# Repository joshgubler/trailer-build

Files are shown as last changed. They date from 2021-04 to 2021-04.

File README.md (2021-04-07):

# Trailer Build

## Introduction

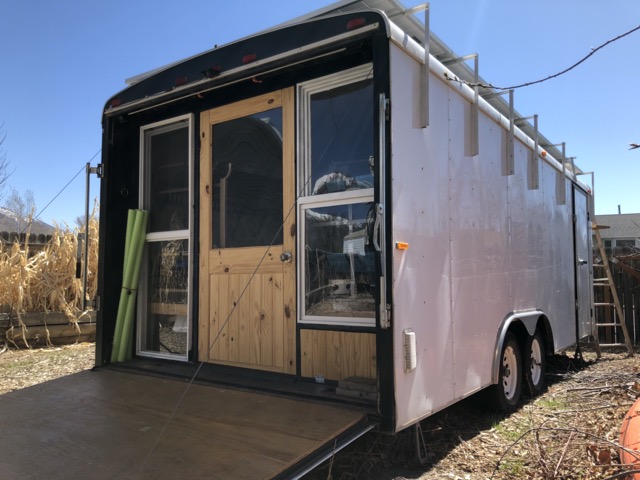
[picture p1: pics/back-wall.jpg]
back wall


It's an 8'x20' car hauler, converted into a travel trailer.

If I could change one thing, I would start with a lighter trailer. Car haulers have massive floor joists which just add unnecessary weight for a travel trailer. However, commercially manufactured travel trailers are poorly built, leak, and fall apart. Utility trailers don't have any of these problems. I expect this thing to last forever.

## Construction

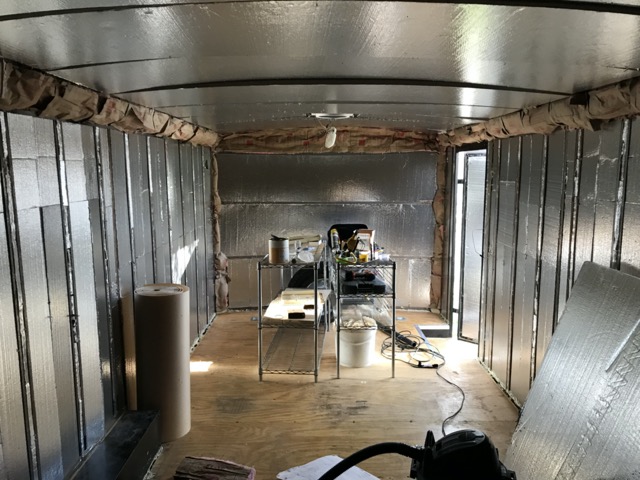
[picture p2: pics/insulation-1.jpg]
insulate spaces


The first thing we did was take all the paneling out and add insulation. 1" solid foam in the walls. 1.5" solid foam in the nose and roof. Batting in the curved corners.

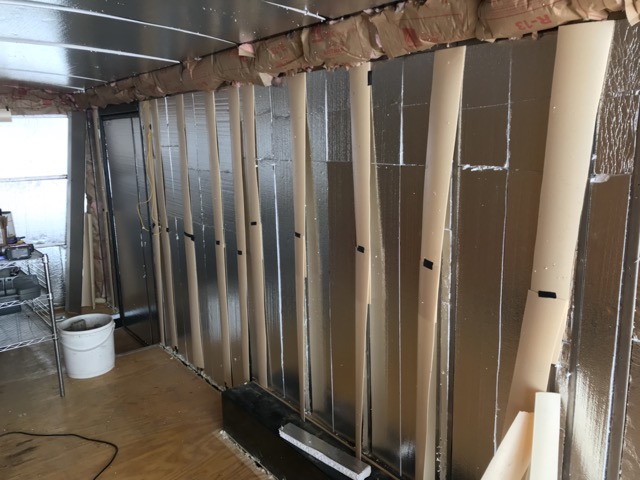
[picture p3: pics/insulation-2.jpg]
insulate metal


Then we covered all the exposed metal with foam strips. This cuts down on heat loss due to conduction through the walls.

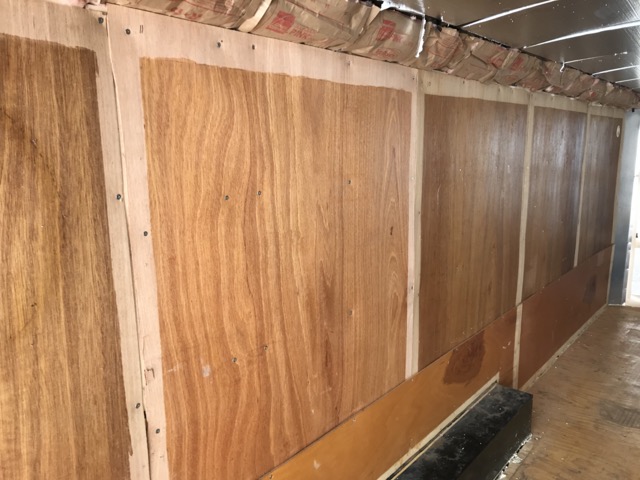
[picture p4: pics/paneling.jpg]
paneling


Then put the paneling back in.

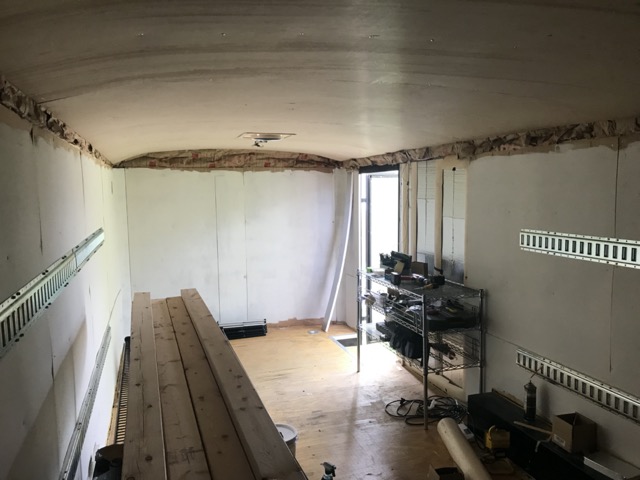
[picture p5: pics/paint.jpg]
paint


A layer of paint and install e-track. E-track gives us flexibility to play with different floor plans.

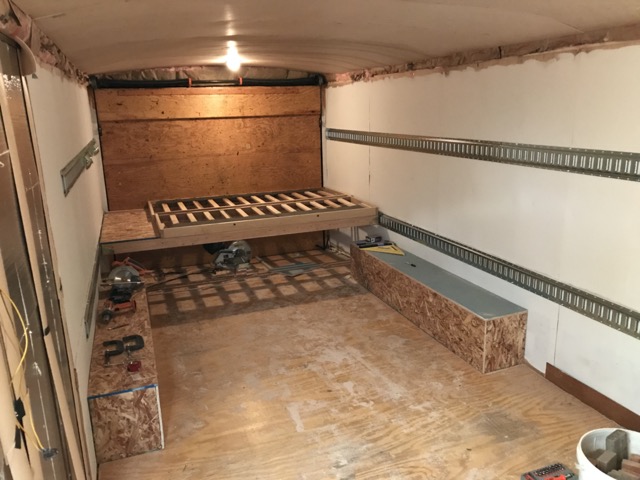
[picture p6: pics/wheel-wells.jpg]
wheel wells


We boxed around the wheel wells to provide support and insulation. And installed the joists for our bed.

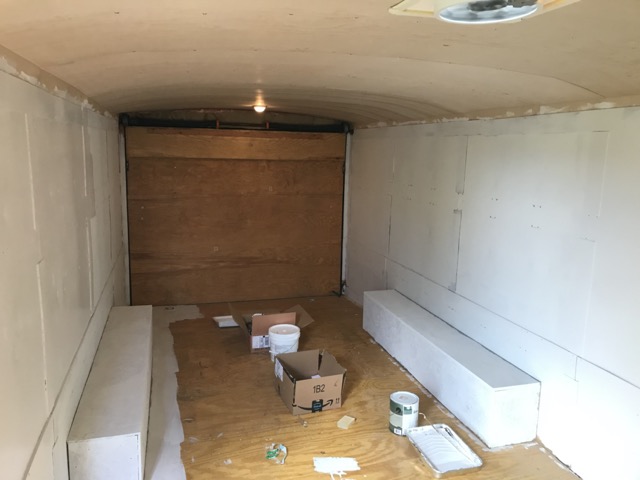
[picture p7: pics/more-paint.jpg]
more paint


I got ahead of myself and had to take the bed and e-track out to finish painting.

## First floor plan

Our initial floor plan had the queen bed at the back, the kitchen in the middle, and the bunk cots in an "L" shape at the front. This worked ok, but we couldn't really use the back door, and the side door was a little congested.

It also put a lot of "under bed storage" at the tail, which isn't where you want the majority of your weight.

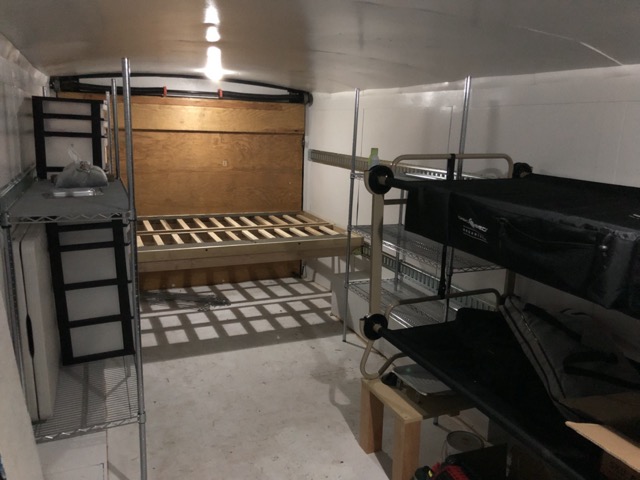
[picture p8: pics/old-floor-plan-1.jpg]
old floor plan


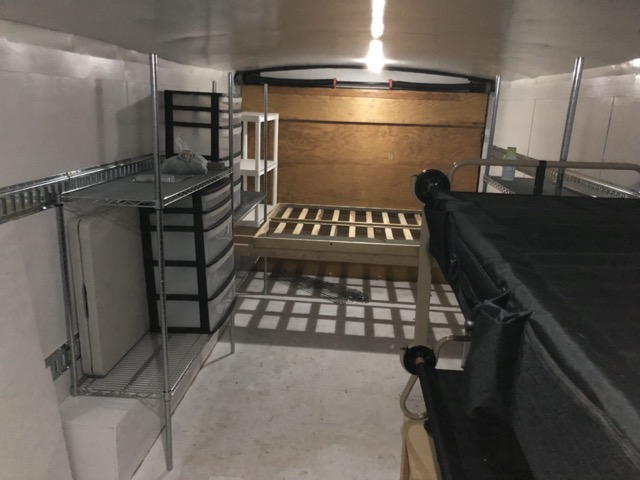
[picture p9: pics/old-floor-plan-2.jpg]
old floor plan


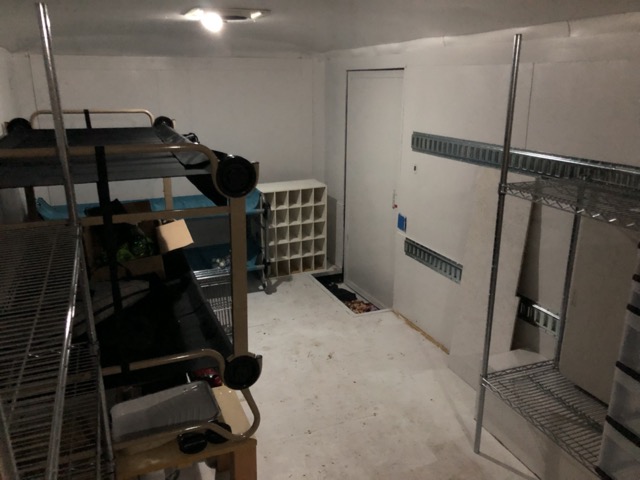
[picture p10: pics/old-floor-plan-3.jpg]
old floor plan


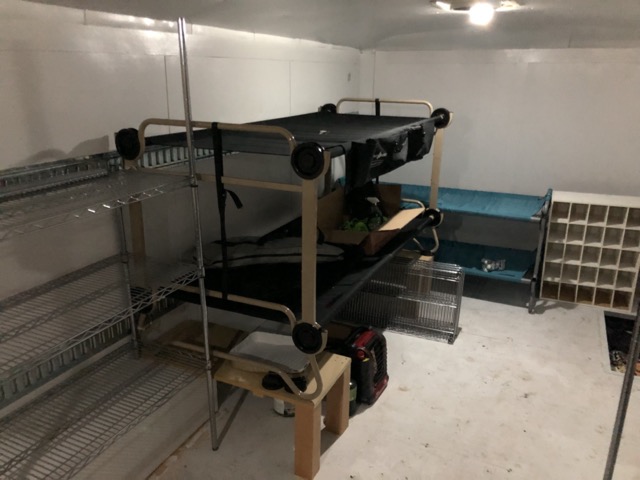
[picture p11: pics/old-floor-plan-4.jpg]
old floor plan


## Final floor plan

### Overview

back wall

We wanted more light, and a second door, but we didn't want to cut holes in the frame or skin. So we built a false wall on the back. This quickly became our main entrance/exit as it's much nicer than the side door on the trailer.

Plans for the back wall are in [Trailer Wall.skp](./Trailer%20Wall.skp).

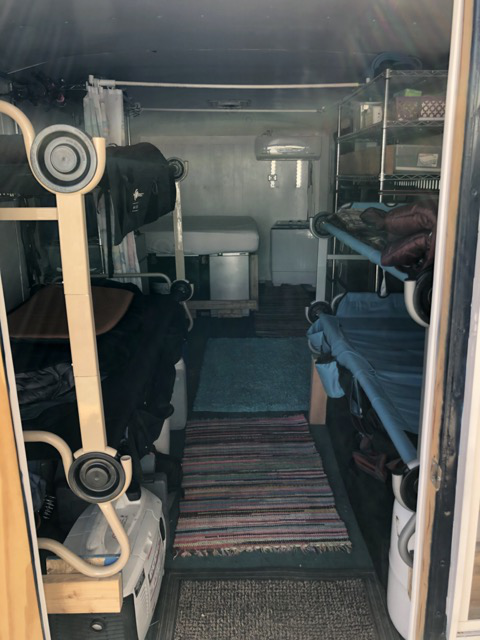
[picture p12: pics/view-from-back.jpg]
view from back


This is looking in the back door. We went with a bunkhouse layout.

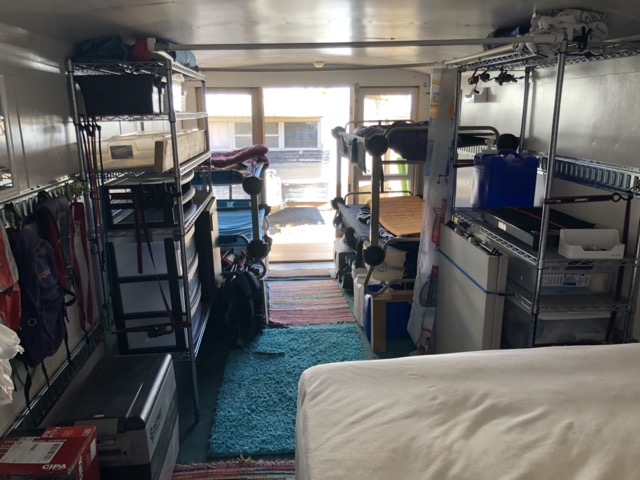
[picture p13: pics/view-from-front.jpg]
view from front


Looking back from the front.

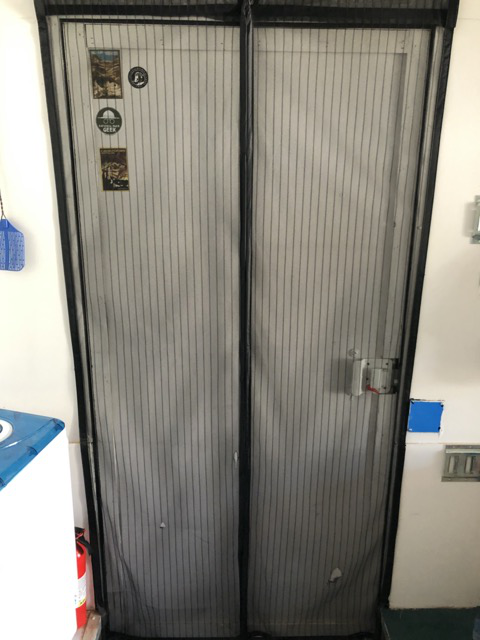
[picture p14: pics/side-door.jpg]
side door


And here's the side door, on the passenger's side, with a "walk through" screen.

### Sleeping

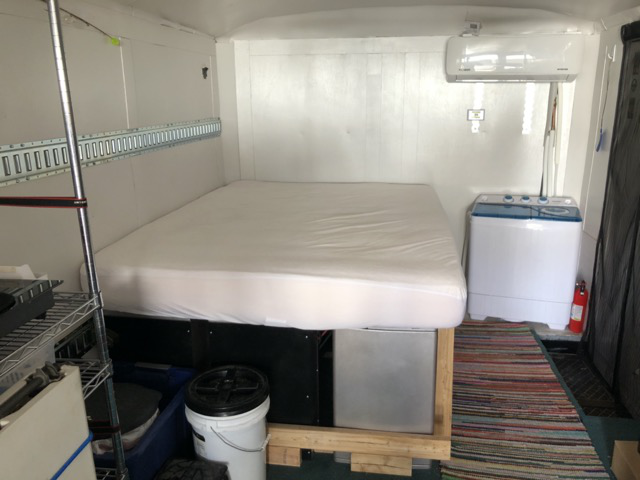
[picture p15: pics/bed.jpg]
queen bed


At the front driver's side, we have a queen size bed, with lots of storage space underneath.

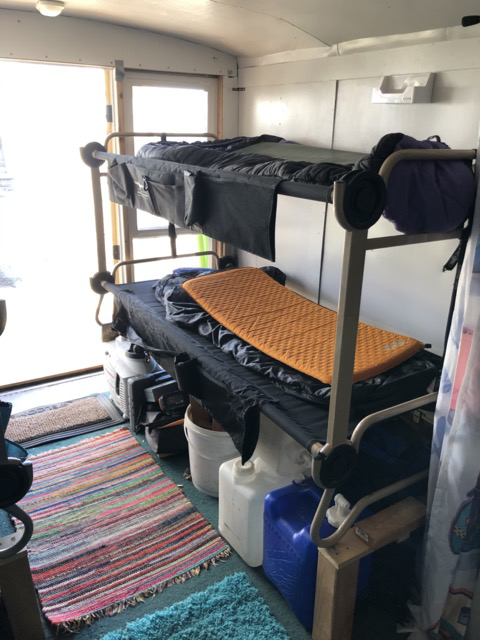
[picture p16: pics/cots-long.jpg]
long cots


At the back driver's side, we have full size disc-o-bed bunk cots for the teenagers.

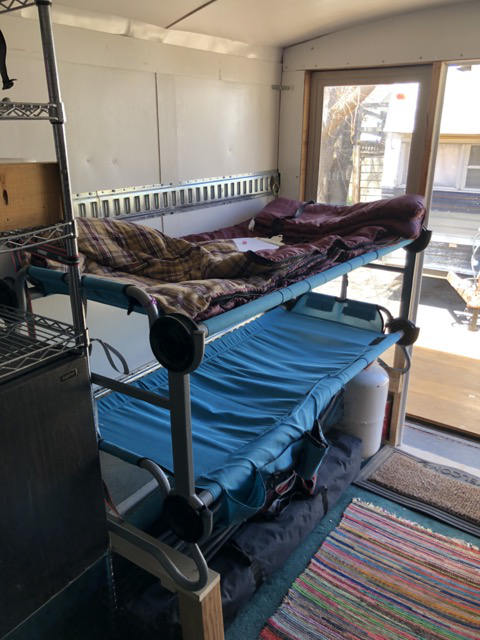
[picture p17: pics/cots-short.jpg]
short cots


And on the passenger's side, slightly shorter "kid size" disc-o-bed bunk cots for the younger ones.

Raising these up gives lots of storage underneath. They're tied back to the e-track so they won't fall off.

### Kitchen

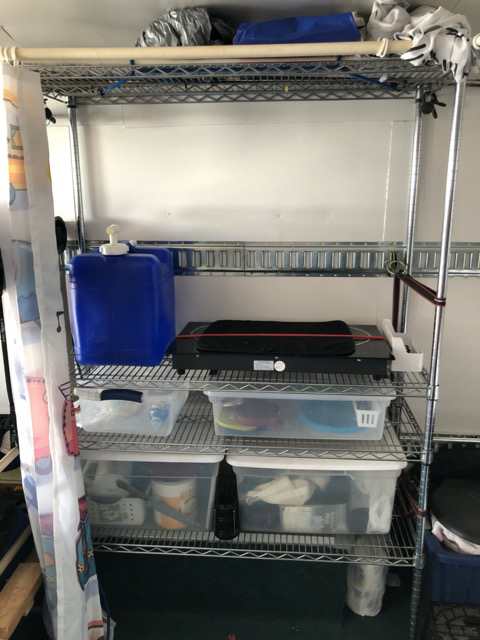
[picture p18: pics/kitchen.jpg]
kitchen


In the middle driver's side, we have our kitchen, including an 1800w induction cooktop. I didn't want to deal with winterizing, so jugs for water; no plumbing.

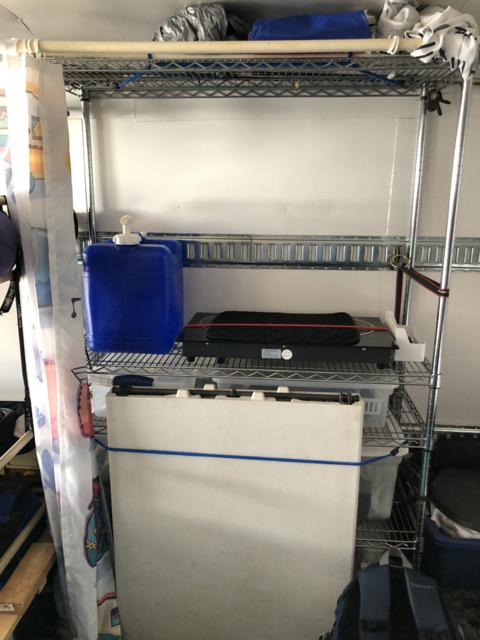
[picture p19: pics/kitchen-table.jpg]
table storage


The folding table stores here during travel.

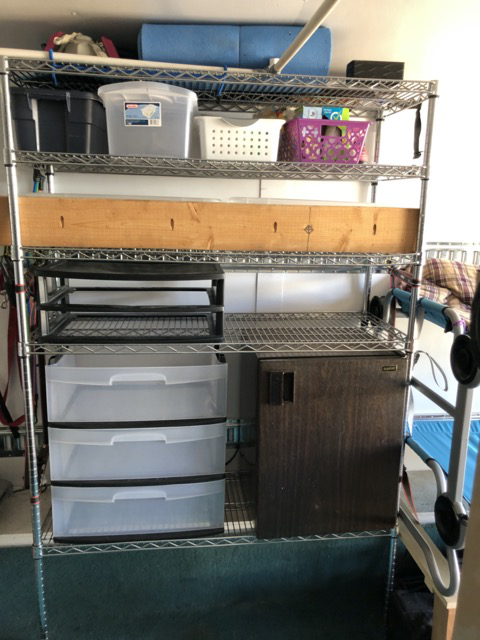
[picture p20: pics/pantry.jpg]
pantry


In the middle passenger's side, we have the pantry. The 2x6 is the lever I use to check trailer tongue weight. It stores here when traveling to lock bins in place.

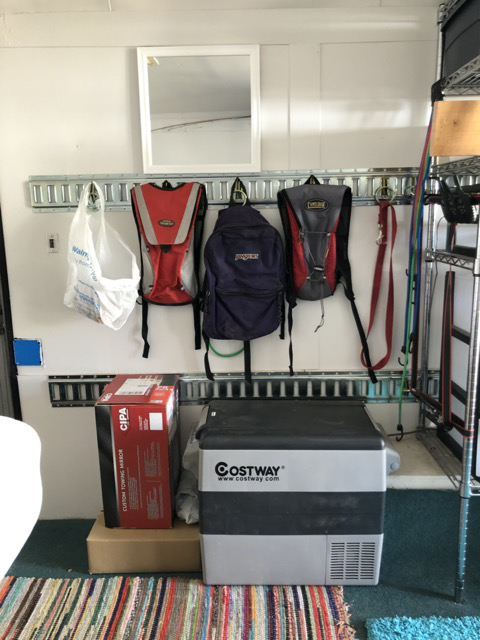
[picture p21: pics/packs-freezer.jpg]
freezer and hiking packs


Also on passenger side, between the pantry and the side door, we have our freezer, mirror, and our "grab and go" storage for coats and packs.

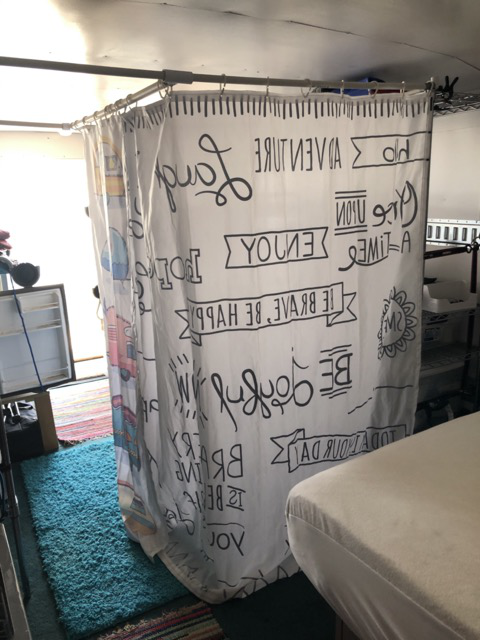
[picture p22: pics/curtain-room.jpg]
curtain-room


Curtains run on a PVC pipe frame to let us separate the space into 3 distinct rooms for privacy when needed, but easily fold away for an open feel. We love having that flexibility to change the space as needed.

### Toilet

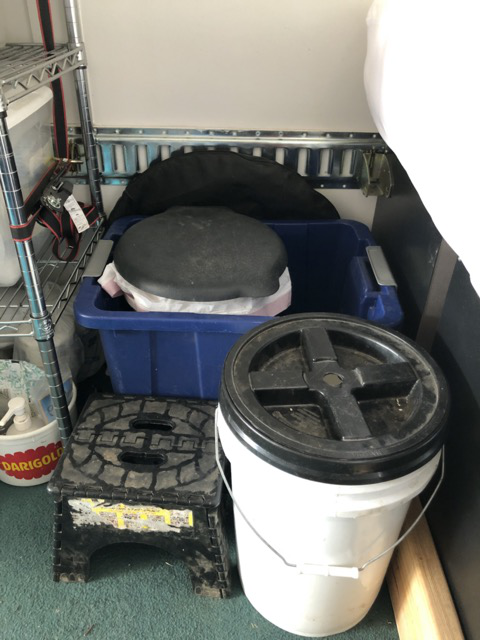
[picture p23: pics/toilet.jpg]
toilet


I've dealt with black water tanks before. They're the worst. A simple composting toilet is much nicer. The extra bucket is full of wood chips to eliminate odor.

Having everything portable lets us set it up in an outdoor pop-up during the day, or in the curtain room at night. It's also easy to throw the whole tote in the truck when we need to empty it, or take a toilet with us on a day adventure.

The whole setup stores here on the driver's side during travel.

## Electrical

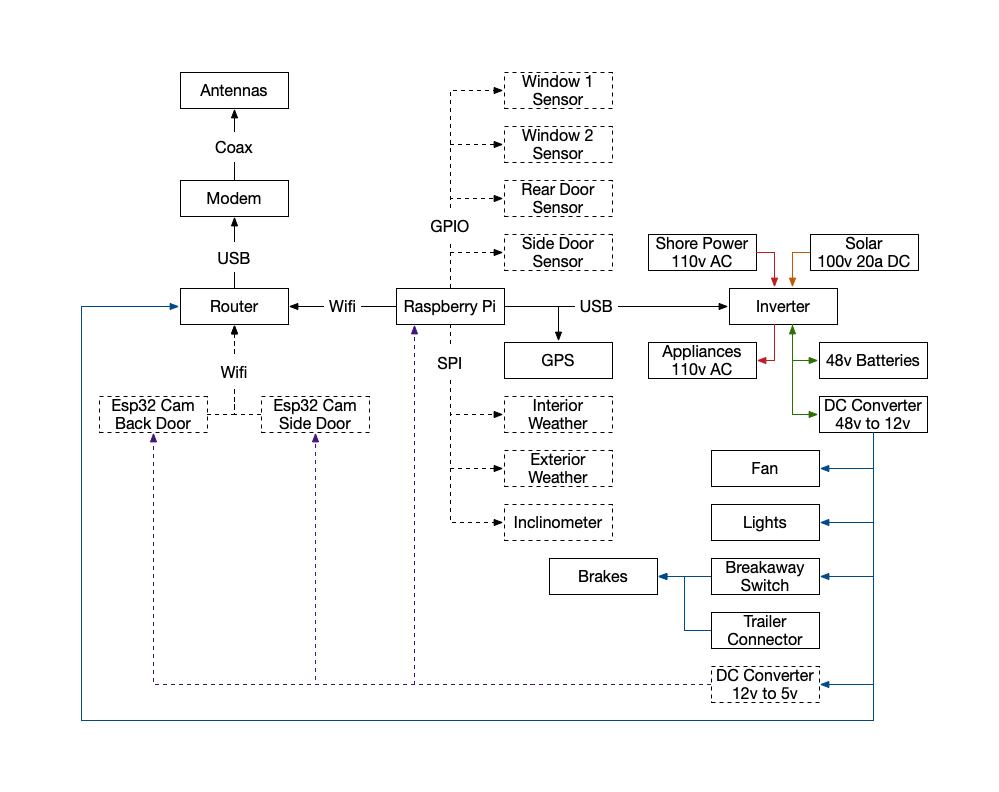
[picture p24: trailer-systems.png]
trailer systems diagram


(Dashed lines are not yet implemented. Colored lines indicate different, incompatible voltages.)

### Batteries

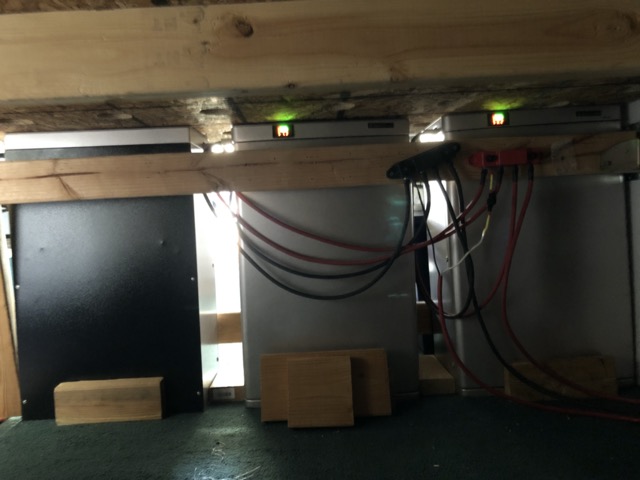
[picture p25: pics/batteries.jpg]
batteries


Under the foot of the queen bed, I have 3 48v Li-ion batteries. Each of these is 79 amp hours. That makes a total of over 11 kwh, or the equivalent of 950 amp hours at 12v.

I used to have these right at the front of the camper, under the head of the queen bed. They are heavy. And having them there pushed my tongue weight too high. Moving them back 5 ft shaved about 200 lbs off the tongue weight. In their new position, I had to build bracing around them to ensure they don't move during travel.

### Inverter/Charger

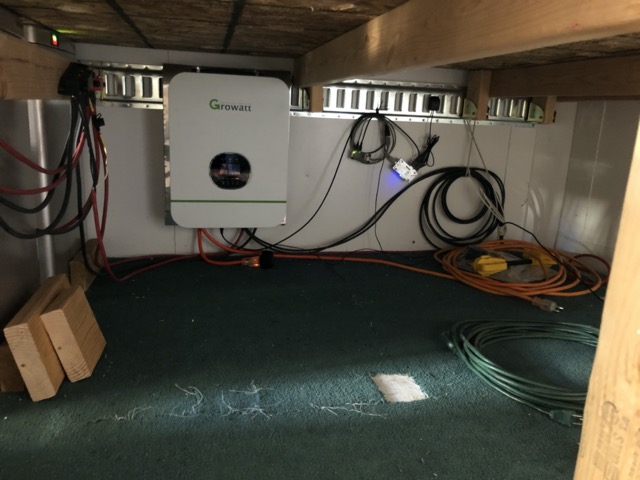
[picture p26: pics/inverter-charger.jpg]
inverter/charger


On the driver's side, just in front of the batteries, I have a Growatt 3kw 48v all-in-one charger/inverter. This connects to solar, batteries, AC in, and AC out. It intelligently routes and converts power between these systems.

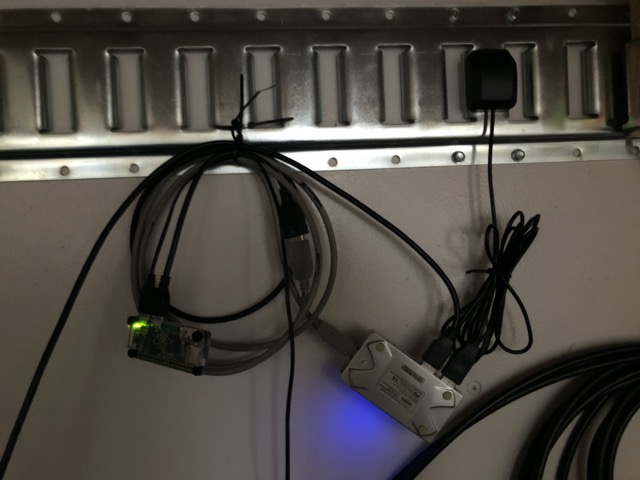
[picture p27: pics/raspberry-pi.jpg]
raspberry-pi


The charger/inverter has a USB modbus interface. I use a raspberry pi zero-w to monitor data from the charger/inverter. It also monitors location/speed data from a USB GPS receiver. The raspberry pi is a flexible platform that I can easily extend in the future to add additional monitoring and controls.

All of this data is made available to an iOS app via a websockets interface.

The raspberry pi also has a VPN client running, connecting back to my own VPN server. This allows me to connect to the pi from anywhere using a client-to-client VPN connection.

The code running on the raspberry pi can be found at [https://github.com/joshgubler/trailer-monitor-rpi/](https://github.com/joshgubler/trailer-monitor-rpi/).

The code for the iOS app can be found at  [https://github.com/joshgubler/trailer-monitor-ios/](https://github.com/joshgubler/trailer-monitor-ios/).

### Wiring

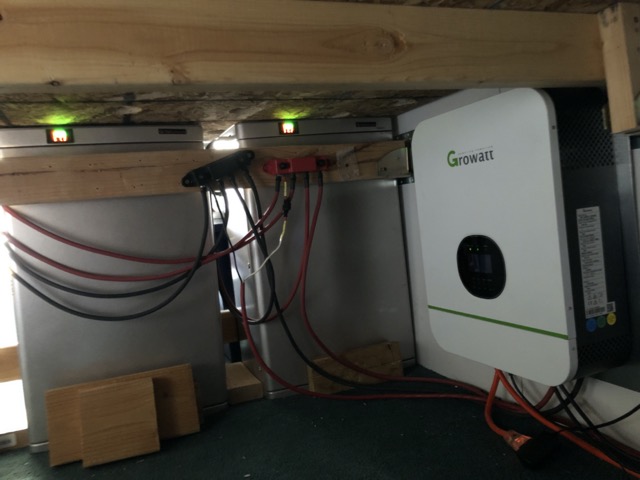
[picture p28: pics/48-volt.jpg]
48 volt wiring


The batteries are connected to the charger/inverter in parallel via 4 awg cables and 250 amp busbars. All cables had to be the same length to ensure that the batteries all get the same charge.

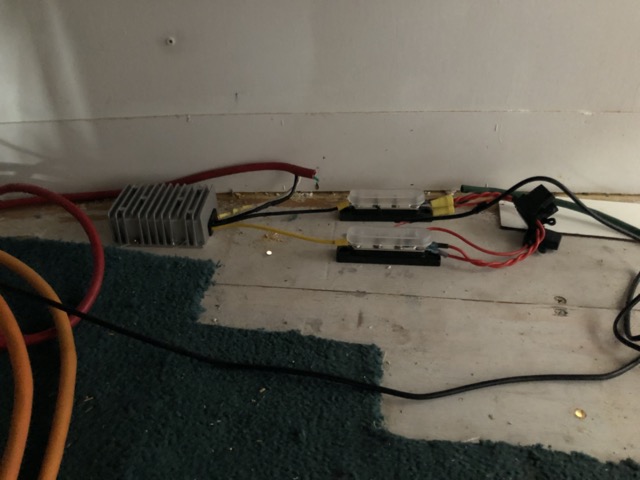
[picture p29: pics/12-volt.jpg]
12 volt wiring


At the front of the trailer, a buck converter steps the 48v power down to 12v. A 100 amp busbar and fuses connect this power to the existing trailer wiring for the fan, lighting, and break-away switch for trailer brakes.

I chose to put this close to where the existing trailer wiring ties in, so that I could use lighter gauge wire to the buck converter. (The same load uses less amps at 48v than at 12v.)

### Solar

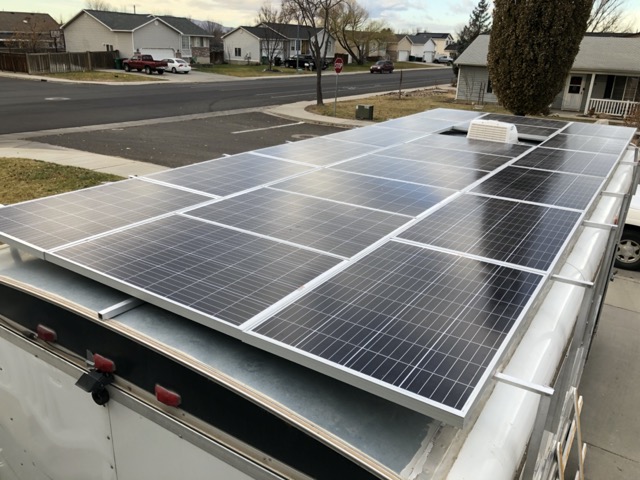
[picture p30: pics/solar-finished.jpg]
solar panels installed


On the roof, I built a rack to which I mounted 20 100w solar panels. The rack is bolted to the trailer frame through the sides of the trailer so that nothing punctures the roof.

Plans for the solar rack and layout are in [Trailer Solar.skp](./Trailer%20Solar.skp).

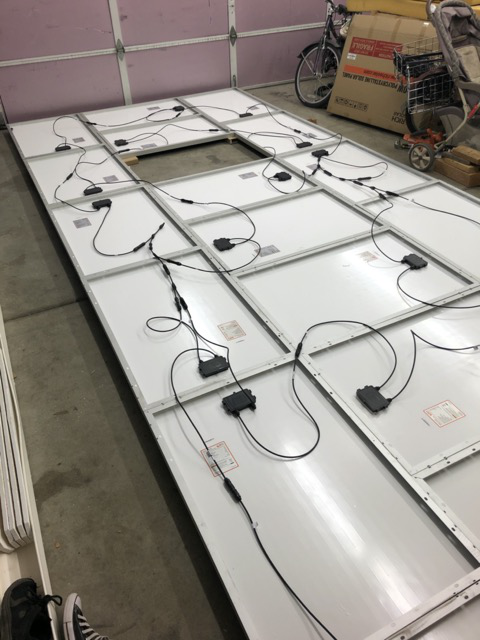
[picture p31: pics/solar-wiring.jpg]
testing solar wiring


I laid everything out in my garage to figure out how everything needed to bolt together, and to figure out wiring.

You can trade amps for volts based on how you wire the panels. I needed to find a configuration that provided more than 48v (my battery voltage) and less than 150v (the max rating of my charger).

I wired the panels into strings of 5 in series, and then 4 strings in parallel (5s4p). This gives me about 20 amps and 100v at peak production.

I considered removing the fan vent cover from the roof of the trailer, adding a 21st panel, and doing a 7s3p configuration. But this would have put the system at 140v, and that's just too close to the 150v max (especially since panels often overproduce when they are cold).

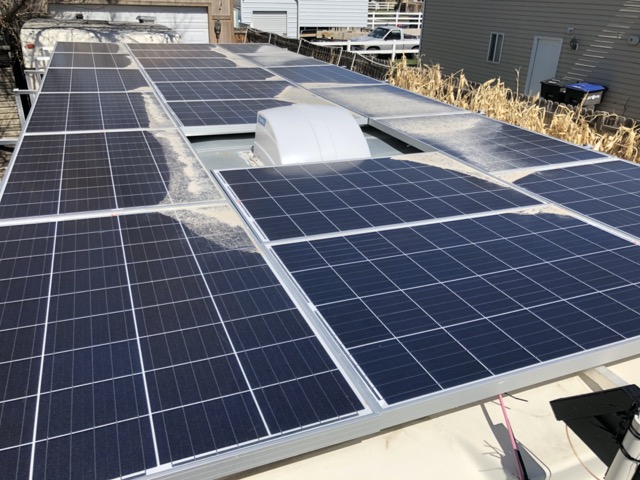
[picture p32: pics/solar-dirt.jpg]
solar panels dirty


Apparently my panels collect dirt. This little bit of dirt killed 70% of my solar production. I was only getting 600w instead of 2kw. 

## AC/Heat

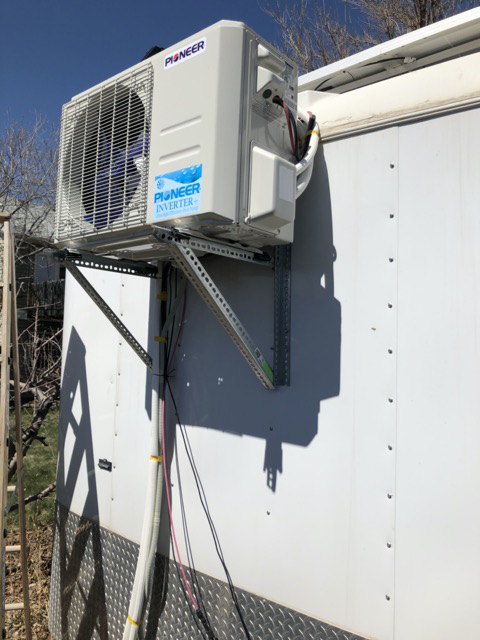
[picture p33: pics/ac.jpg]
outside ac/heat


I mounted a pioneer mini split air conditioner and heat pump on the front of the trailer. The bracket is bolted to the trailer frame. All of the wiring and freon lines run down the outside of the trailer and enter through holes in the floor, so that the walls stay waterproof.

Plans for the mounting bracket are in [Trailer AC Bracket.skp](./Trailer%20AC%20Bracket.skp)

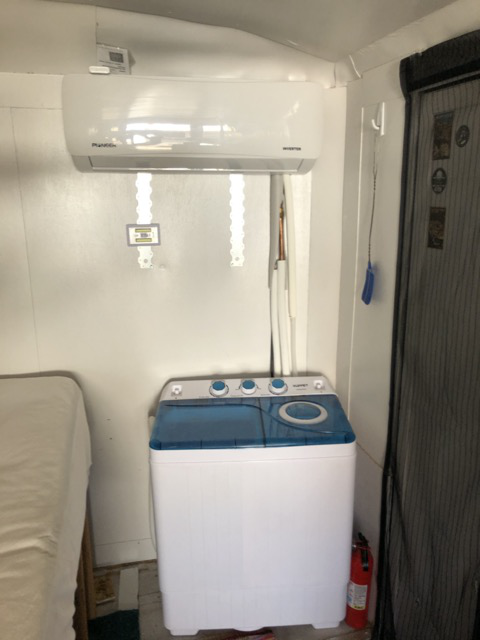
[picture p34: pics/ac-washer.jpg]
inside ac/heat and washer


The indoor unit for the mini split is mounted on passenger side of the front wall. Below the mini split is a small washing machine.

The mini split draws about 1000 watts when it's working hard. Once everything gets to temperature, and it's just maintaining, draw drops to about 400 watts. This was the most important factor in determining solar and battery capacity.

With this setup, I can run the mini split in either heat or cool mode 24/7 as long as I get enough sunlight during the day. (I can also use a generator or plug in to campground power if needed.)

## Internet

For internet, I use an [Instyconnect Mobile Internet Router](https://instyconnect.com). This device is comparable in price to other options, but uses newer and much higher quality components. The Instyconnect also organizes those components in a much better configuration than other options, minimizing inherent signal loss.

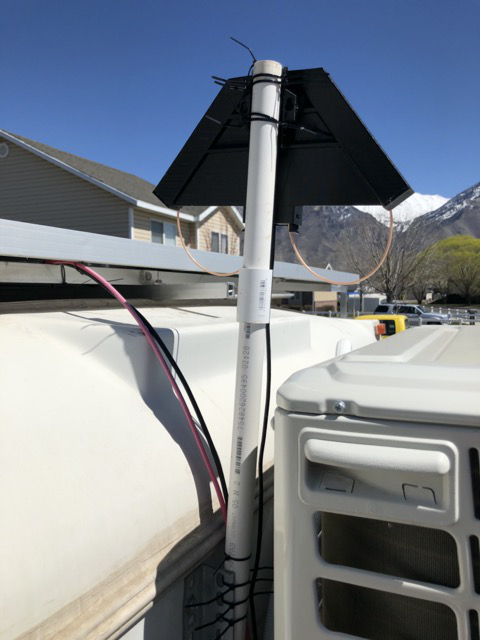
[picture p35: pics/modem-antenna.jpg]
modem and antenna


The antenna and modem are attached to the AC mounting bracket outside the trailer.

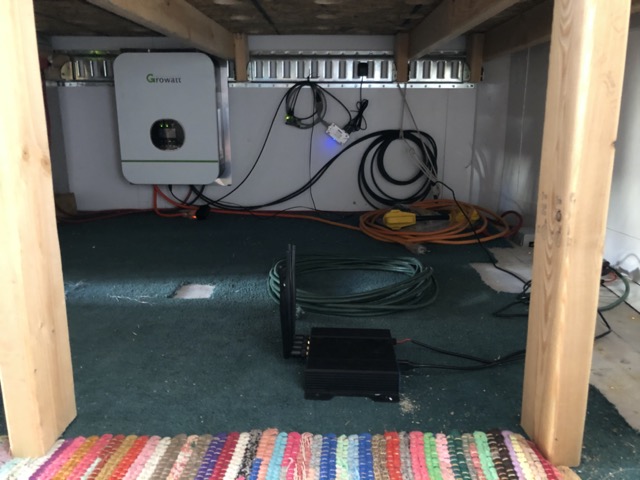
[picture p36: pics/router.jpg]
wifi router


The wifi router is inside the trailer and is connected to the 12v busbars.

## Conclusion

We've had a lot of fun working on this project. As you can see, it isn't finish carpentry. But it's flexible and it meets our needs. There have been fun problems to solve, and we've learned a ton. As I said earlier, the one thing I would change would be to start with a lighter trailer.

It'll be a great home base for the many adventures we have planned.

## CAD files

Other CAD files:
Trailer AC Bracket.skp
Trailer Solar.skp
Trailer Wall.skp
